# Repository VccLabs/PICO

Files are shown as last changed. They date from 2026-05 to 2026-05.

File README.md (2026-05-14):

# PICO

This repo is still under construction, all related files will be released very soon!
<div align="center">

PICO Development Board

# PICO

### A Tiny and Powerful Arduino-Compatible Development Board for Makers






</div>

---

## Introduction

**PICO**: a tiny but powerful Arduino-compatible development board built for makers who don't want to compromise. Measuring just **17.78 × 15.24 mm (0.7" × 0.6")**, PICO is small enough to disappear into wearables, drones, and pocket-sized prototypes, yet packs enough capability to drive serious projects.

At its core, PICO runs the proven **ATmega32U4** microcontroller and exposes **14 GPIOs**, giving you plenty of room to connect sensors, displays, motors, and just about anything else you can dream up. A built-in **WS2812 addressable RGB LED** on pin D5 adds a splash of color for status indication or pure fun. The board is fully **breadboard compatible**, so you can prototype quickly without extra adapters.

PICO is **open source** by design. All schematics, PCB layouts, and source files are available in this repository, so you're free to learn from it, modify it, or build on top of it.

---

## Features

- **Ultra-compact**: 17.78 × 15.24 mm (0.7" × 0.6") footprint
- **ATmega32U4**: microcontroller with native USB
- **14 GPIOs**: including PWM, ADC, I²C, SPI, and UART
- **Built-in WS2812 RGB LED**: (addressable, on pin D5)
- **Breadboard friendly**: castellated pins
- **Multiple power options**: USB and VIN
- **Arduino IDE compatible**: program it like any Arduino Leonardo
- **Fully open source**: schematics, PCB, and code freely available

---

## Specifications

| Category | Specification |
|---|---|
| **Microcontroller** | ATmega32U4 |
| **Architecture** | 8-bit AVR |
| **Clock Speed** | 16 MHz |
| **Flash Memory** | 32 KB (4 KB used by bootloader) |
| **SRAM** | 2.5 KB |
| **EEPROM** | 1 KB |
| **GPIO Pins** | 14 <!-- TODO: confirm digital vs analog split --> |
| **PWM Channels** | 3 (D4 D10 D11) |
| **Analog Inputs** | 5 (D4 D12 A0 A1 A2) |
| **Communication** | USB, I²C, SPI, UART |
| **Operating Voltage** | 5 V |
| **Input Voltage (VIN)** | 7V~15V or power from USB port |
| **DC Current per I/O Pin** | 40mA |
| **Onboard LED** | 1× WS2812 addressable RGB (1 × 1 mm) on D5 |
| **USB Connector** | USB Type-C (**Use USB Typ-A to Type-C cable, I forgot to add the 5.1K resistord on CC pins 🐸**) |
| **Dimensions** | 17.78 × 15.24 mm (0.7" × 0.6") |
| **Weight** | ~1.1 g |

---

## Pinout

<div align="center">

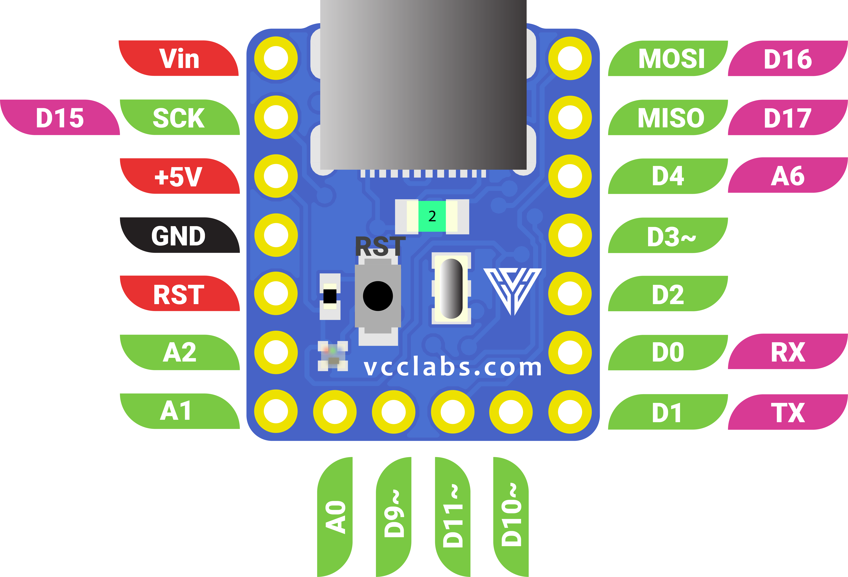
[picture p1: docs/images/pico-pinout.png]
PICO Pinout Diagram


</div>

| Pin | Type | Alternate Functions | Notes |
|---|---|---|---|
| Vin | Power (input)  | — | 7–15 V external supply |
| +5V | Power (output) | — | Regulated 5 V output |
| GND | Ground | — | Common ground |
| RST | Reset | — | Active low; pull to GND to reset |
| SCK | Digital | D15, SPI Clock | SPI bus |
| MOSI  | Digital | D16, SPI Master-Out | SPI bus |
| MISO  | Digital | D17, SPI Master-In | SPI bus |
| D4 | Digital | A6 (Analog In) | ADC capable |
| D3 ~  | Digital | PWM | PWM output |
| D2 | Digital | — | General-purpose I/O |
| D0 | Digital | RX (UART) | Serial receive |
| D1 | Digital | TX (UART) | Serial transmit |
| A0 | Analog | Digital I/O | ADC input |
| A1 | Analog | Digital I/O | ADC input |
| A2 | Analog | Digital I/O | ADC input |
| D9 ~  | Digital | PWM | PWM output |
| D10 ~ | Digital | PWM | PWM output |
| D11 ~ | Digital | PWM | PWM output |
| D5 | Digital | WS2812 RGB LED (onboard) | Connected to onboard RGB LED |

---

## Getting Started

### 1. Install the Arduino IDE

Download and install the latest **[Arduino IDE](https://www.arduino.cc/en/software)** (version 2.x recommended).

### 2. Add the PICO Board

<!-- TODO: confirm — does PICO work out-of-the-box as "Arduino Leonardo", or do you provide a custom board package? -->

In Arduino IDE, go to **Tools → Board → Board Manager** and select **Arduino Leonardo**, PICO is fully Leonardo-compatible.

### 3. Connect PICO

Plug PICO into your computer using a USB cable (**Use USB Typ-A to Type-C cable, I forgot to add the 5.1K resistord on CC pins 🐸**). The onboard RGB LED will light up briefly to confirm power.

###  Using FastLED

If you prefer **[FastLED](https://github.com/FastLED/FastLED)** over Adafruit NeoPixel, PICO works just as well with it. FastLED is a powerful, performance-focused library with built-in color palettes, HSV support, and smooth animation helpers.

### Install FastLED

In the Arduino IDE, go to **Sketch → Include Library → Manage Libraries…**, search for **FastLED**, and click **Install**.

### 4. Upload Your First Sketch

**Blink LED using FastLED library (Example from the library itself, don't forget to change the Data pin to D5):**

```cpp
#include <Arduino.h>
#include <FastLED.h>

// How many leds do we have?
#define NUM_LEDS 1

#define DATA_PIN 5 // LED pin
#define CLOCK_PIN 13

// Define the array of leds
CRGB leds[NUM_LEDS];

void setup() { 
    //Serial.begin(9600);
    //Serial.println("BLINK setup starting");

    FastLED.addLeds<NEOPIXEL, DATA_PIN>(leds, NUM_LEDS); 
}

void loop() { 
  //Serial.println("BLINK");
  
  // Turn the LED on, then pause
  leds[0] = CRGB::Red;
  FastLED.show();
  delay(500);
  
  // Now turn the LED off, then pause
  leds[0] = CRGB::Black;
  FastLED.show();
  delay(500);
}
```

Click **Upload** — and you're up and running. 

---

## Hardware

All hardware design files are open and available in the [`/hardware`](hardware) folder:

- **Schematics** — `hardware/PICO V1.0.pdf.pdf`
- **PCB Files** — `hardware/pcb/` (Eagle source files)

> Designed in **Eagle**. Feel free to fork and remix.

---

## Onboard RGB LED

PICO features a single **WS2812B addressable RGB LED** connected to **digital pin D5**. Use the [Adafruit NeoPixel](https://github.com/adafruit/Adafruit_NeoPixel) or [FastLED](https://github.com/FastLED/FastLED) libraries to control it.

See [`examples/01_Blink_RGB`](examples/01_Blink_RGB) for a minimal working sketch.

---

## Powering PICO

PICO can be powered in two ways:

| Source | Voltage | Notes |
|---|---|---|
| **USB** | 5 V | Plug-and-play for programming and power |
| **VIN pin** | 7V~15V | For battery or external supply |

> ⚠️ Do **not** apply power to USB and VIN simultaneously unless you understand the implications.

---

##  Community & Support

Got questions, ideas, or want to share what you built with PICO?

-  **Discussions**: [GitHub Discussions](https://github.com/VccLabs/PICO/discussions)
-  **Issues / Bugs**: [Open an issue](https://github.com/VccLabs/PICO/issues)
-  **Website**: [vcclabs.com](https://vcclabs.com)
-  **Email**: thevcclabs@gmail.com

---

## Contributing

Contributions are welcome! Whether it's a bug fix, a new example sketch, or documentation improvements, feel free to open a pull request.

---

## License

- **Software & examples** are licensed under the [MIT License](LICENSE).
- **Hardware design files** are licensed under the [Creative Commons Attribution 4.0 International License (CC BY 4.0)](https://creativecommons.org/licenses/by/4.0/).

You are free to use, modify, and distribute - including for commercial purposes - provided you credit **Vcc Labs** as the original creator.

---
https://github.com/fastled/fastled
## 🙏 Acknowledgments

PICO was made possible thanks to:

- The **78 backers** who supported us on [Kickstarter](https://www.kickstarter.com/projects/vcclabs/pico-a-tiny-and-powerful-development-board-for-makers) 🚀
- The open-source hardware community
- The [Arduino](https://arduino.cc), [Sparkfun](https://sparkfun.com), [FastLED](https://github.com/fastled/fastled), and [Adafruit](https://adafruit.com) teams for their incredible libraries and tools

---

<div align="center">

**Built with ❤️ by [Vcc Labs](https://vcclabs.com)**

</div>

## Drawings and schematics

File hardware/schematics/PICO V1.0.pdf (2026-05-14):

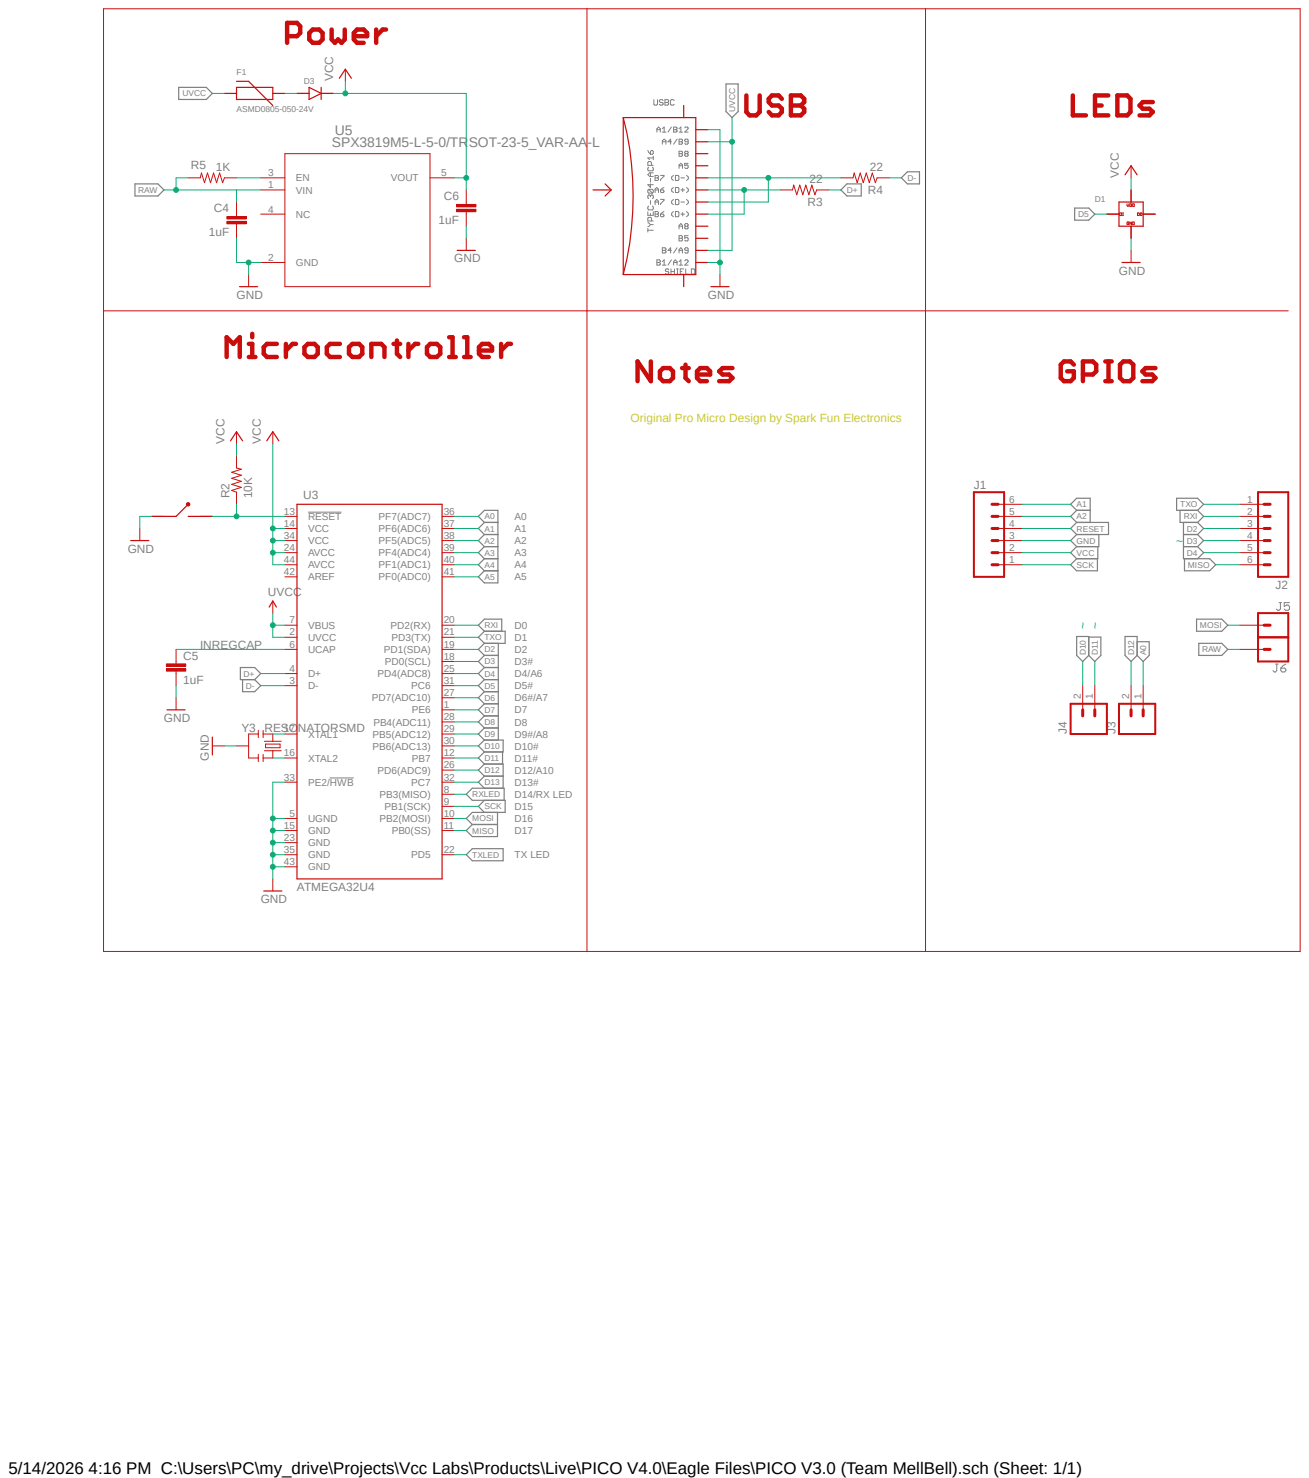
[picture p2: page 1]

Original Pro Micro Design by Spark Fun Electronics

5/14/2026 4:16 PM C:\Users\PC\my_drive\Projects\Vcc Labs\Products\Live\PICO V4.0\Eagle Files\PICO V3.0 (Team MellBell).sch (Sheet: 1/1)

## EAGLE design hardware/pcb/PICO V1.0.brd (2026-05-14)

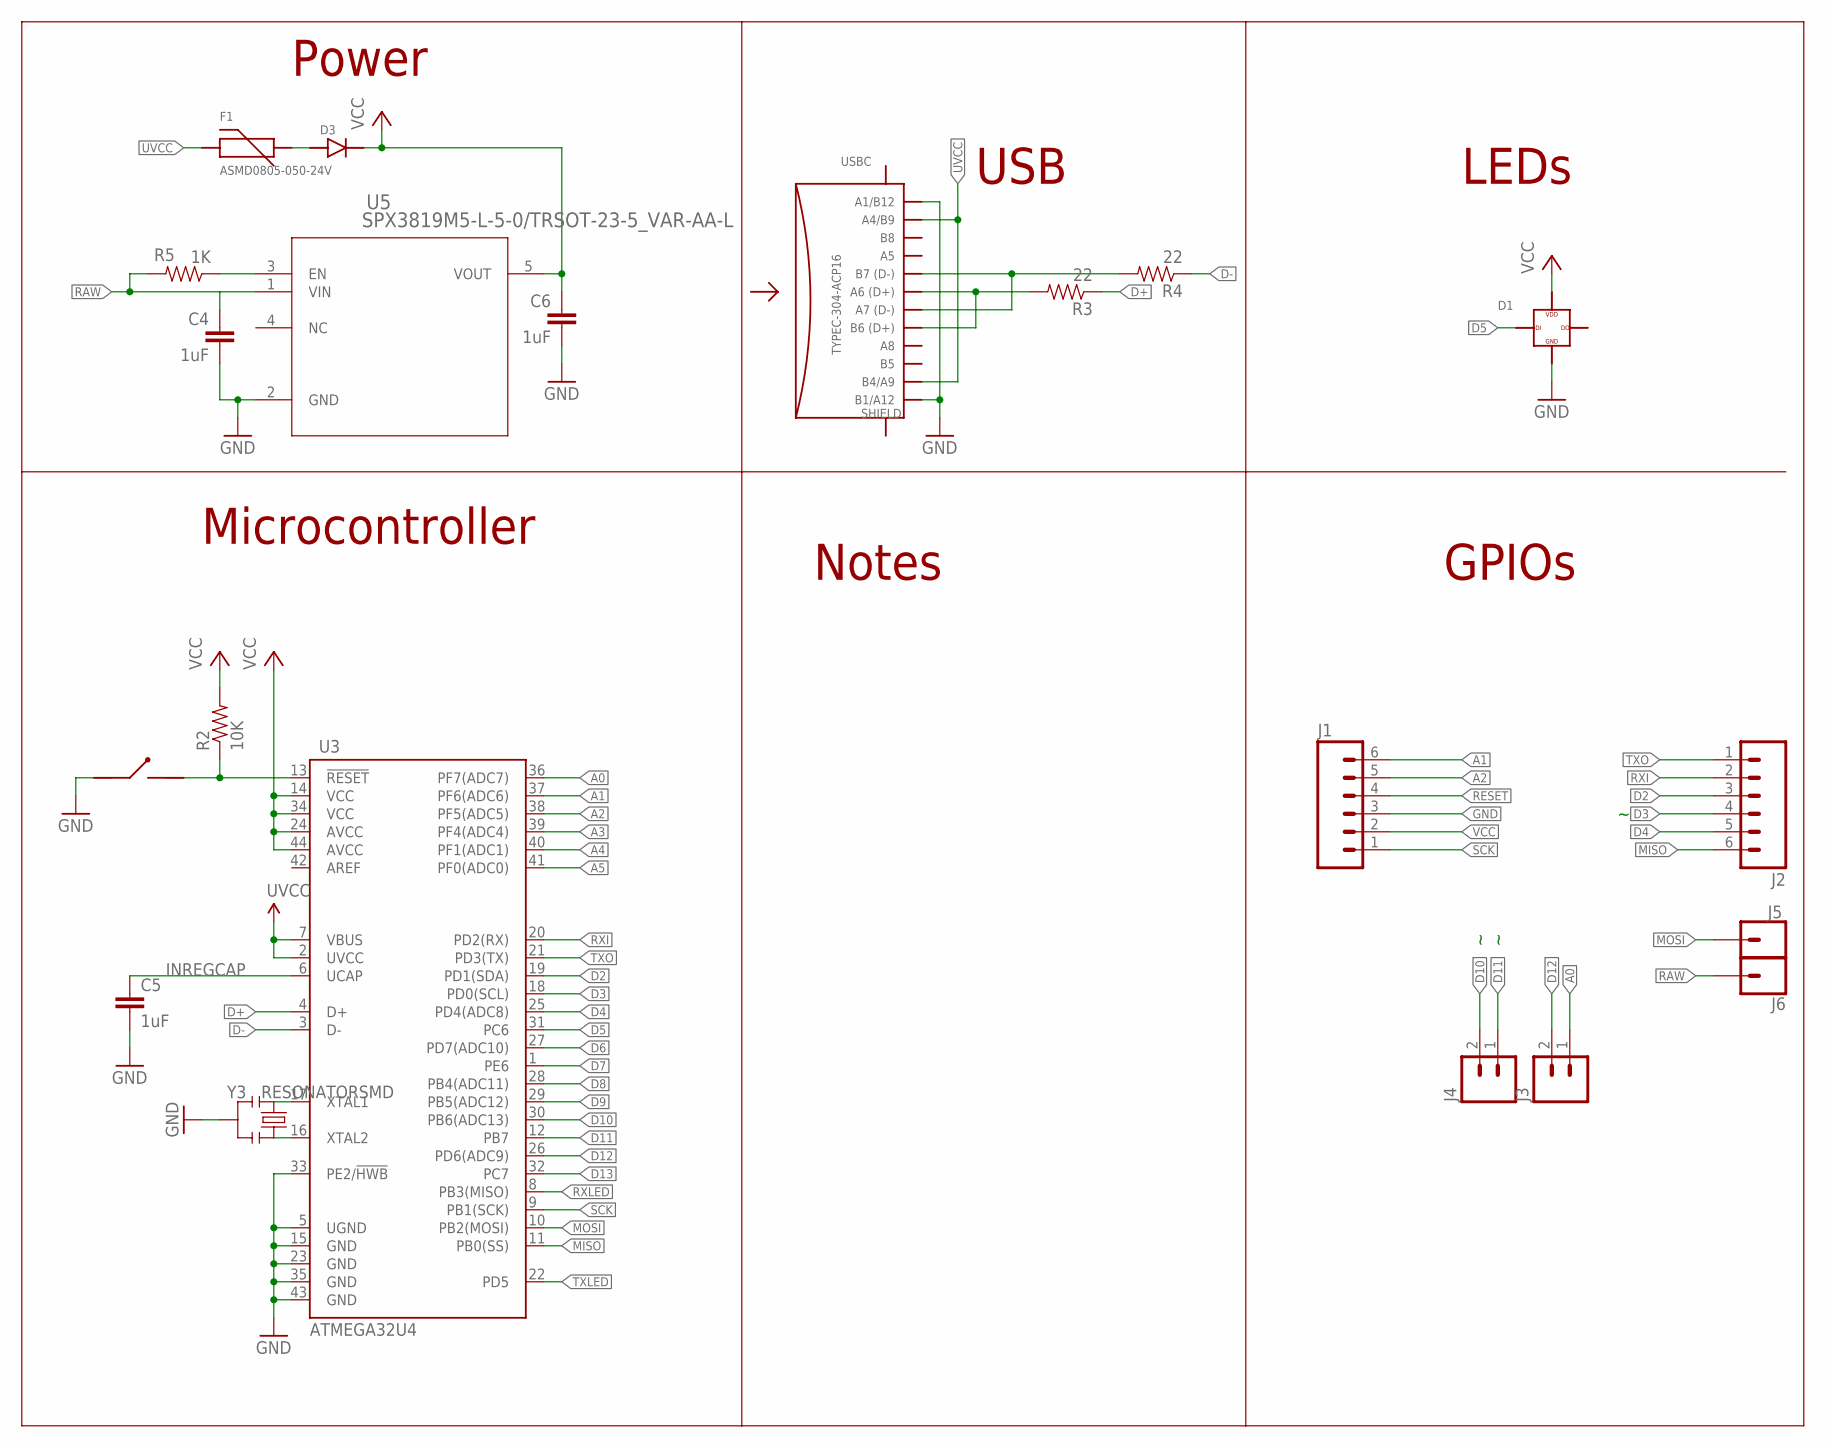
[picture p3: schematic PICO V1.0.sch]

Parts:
C4, C5, C6: 1uF; 0402-CAP
D1: XL-1010RGBC-WS2812B
D3: 1N4148W-TP
F1: ASMD0805-050-24V
J1, J2: M06SILK_FEMALE_PTH; 1X06
J3, J4: M02PTH; 1X02
J5, J6: CONN_01; 1X01
R2: 10K; 0402-RES
R3, R4: 22; 0402-RES
R5: 1K; 0402-RES
S1: B3U-1000P
U3: ATMEGA32U4; QFN-44-NOPAD_1:1-OUTFAKES
U5: SPX3819M5-L-5-0/TRSOT-23-5_VAR-AA-L; TPSPX3819M5-L-5-0/3
USBC: TYPEC-304-ACP16
Y3: RESONATORSMD; RESONATOR-SMD

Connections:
A0: J3.1, U3.36 (PF7(ADC7))
A1: J1.6, U3.37 (PF6(ADC6))
A2: J1.5, U3.38 (PF5(ADC5))
A3: U3.39 (PF4(ADC4))
A4: U3.40 (PF1(ADC1))
A5: U3.41 (PF0(ADC0))
D2: J2.3, U3.19 (PD1(SDA))
D3: J2.4, U3.18 (PD0(SCL))
D4: J2.5, U3.25 (PD4(ADC8))
D5: D1.4, U3.31 (PC6)
D6: U3.27 (PD7(ADC10))
D7: U3.1 (PE6)
D8: U3.28 (PB4(ADC11))
D9: U3.29 (PB5(ADC12))
D10: J4.2, U3.30 (PB6(ADC13))
D11: J4.1, U3.12 (PB7)
D12: J3.2, U3.26 (PD6(ADC9))
D13: U3.32 (PC7)
D+: R3.1, U3.4 (D+)
D-: R4.1, U3.3 (D-)
GND: C4.2, C5.2, C6.2, D1.3, J1.3, S1.1, U3.5 (UGND), U3.15 (GND), U3.23 (GND), U3.33 (PE2/!HWB), U3.35 (GND), U3.43 (GND), U5.2 (GND), USBC.A1/B12, USBC.B1/A12, Y3.2
INREGCAP: C5.1, U3.6 (UCAP)
MISO: J2.6, U3.11 (PB0(SS))
MOSI: J5.1, U3.10 (PB2(MOSI))
unnamed: U3.16 (XTAL2), Y3.3
unnamed: U3.17 (XTAL1), Y3.1
unnamed: R5.1, U5.3 (EN)
unnamed: D3.1, F1.2
unnamed: R3.2, USBC.A6, USBC.B6
unnamed: R4.2, USBC.A7, USBC.B7
RAW: C4.1, J6.1, R5.2, U5.1 (VIN)
RESET: J1.4, R2.1, S1.2, U3.13 (!RESET)
RXI: J2.2, U3.20 (PD2(RX))
RXLED: U3.8 (PB3(MISO))
SCK: J1.1, U3.9 (PB1(SCK))
TXLED: U3.22 (PD5)
TXO: J2.1, U3.21 (PD3(TX))
UVCC: F1.1, U3.2 (UVCC), U3.7 (VBUS), USBC.A4/B9, USBC.B4/A9
VCC: C6.1, D1.2, D3.2, J1.2, R2.2, U3.14 (VCC), U3.24 (AVCC), U3.34 (VCC), U3.44 (AVCC), U5.5 (VOUT)

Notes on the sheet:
Power
USB
LEDs
Microcontroller
GPIOs
Notes

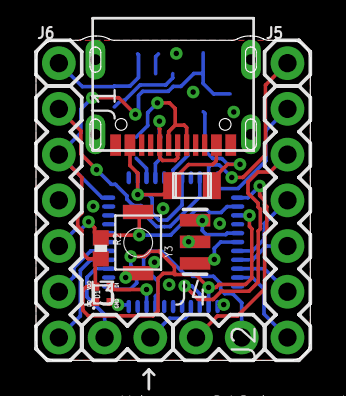
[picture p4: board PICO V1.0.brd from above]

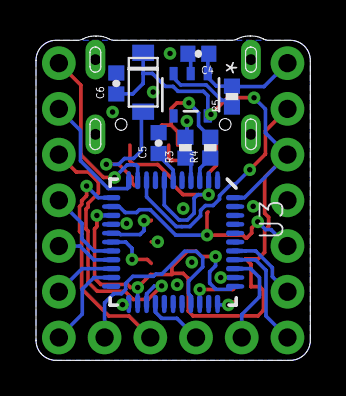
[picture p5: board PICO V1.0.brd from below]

Board: 2 copper layers, 15.2 x 18.0 mm, 21 parts (9 on the bottom side), 29 nets.

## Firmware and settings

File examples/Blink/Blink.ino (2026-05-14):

/// @file    Blink.ino
/// @brief   Blink the first LED of an LED strip
/// @example Blink.ino

#include <Arduino.h>
#include <FastLED.h>

// How many leds in your strip?
#define NUM_LEDS 1

// For led chips like WS2812, which have a data line, ground, and power, you just
// need to define DATA_PIN.  For led chipsets that are SPI based (four wires - data, clock,
// ground, and power), like the LPD8806 define both DATA_PIN and CLOCK_PIN
// Clock pin only needed for SPI based chipsets when not using hardware SPI
#define DATA_PIN 5
#define CLOCK_PIN 13

// Define the array of leds
CRGB leds[NUM_LEDS];

void setup() { 
    //Serial.begin(9600);
    //Serial.println("BLINK setup starting");
    
    // Uncomment/edit one of the following lines for your leds arrangement.
    // ## Clockless types ##
    FastLED.addLeds<NEOPIXEL, DATA_PIN>(leds, NUM_LEDS);  // GRB ordering is assumed
    
    //Serial.println("BLINK setup complete");
    // FastLED.addLeds<SM16824E, DATA_PIN, RGB>(leds, NUM_LEDS);  // RGB ordering (uses SM16824EController)
    // FastLED.addLeds<SM16703, DATA_PIN, RGB>(leds, NUM_LEDS);
    // FastLED.addLeds<TM1829, DATA_PIN, RGB>(leds, NUM_LEDS);
    // FastLED.addLeds<TM1812, DATA_PIN, RGB>(leds, NUM_LEDS);
    // FastLED.addLeds<TM1809, DATA_PIN, RGB>(leds, NUM_LEDS);
    // FastLED.addLeds<TM1804, DATA_PIN, RGB>(leds, NUM_LEDS);
    // FastLED.addLeds<TM1803, DATA_PIN, RGB>(leds, NUM_LEDS);
    // FastLED.addLeds<UCS1903, DATA_PIN, RGB>(leds, NUM_LEDS);
    // FastLED.addLeds<UCS1903B, DATA_PIN, RGB>(leds, NUM_LEDS);
    // FastLED.addLeds<UCS1904, DATA_PIN, RGB>(leds, NUM_LEDS);
    // FastLED.addLeds<UCS2903, DATA_PIN, RGB>(leds, NUM_LEDS);
    // FastLED.addLeds<WS2812, DATA_PIN, RGB>(leds, NUM_LEDS);  // GRB ordering is typical
    // FastLED.addLeds<WS2852, DATA_PIN, RGB>(leds, NUM_LEDS);  // GRB ordering is typical
    // FastLED.addLeds<WS2812B, DATA_PIN, RGB>(leds, NUM_LEDS);  // GRB ordering is typical
    // FastLED.addLeds<GS1903, DATA_PIN, RGB>(leds, NUM_LEDS);
    // FastLED.addLeds<SK6812, DATA_PIN, RGB>(leds, NUM_LEDS);  // GRB ordering is typical
    // FastLED.addLeds<SK6822, DATA_PIN, RGB>(leds, NUM_LEDS);
    // FastLED.addLeds<APA106, DATA_PIN, RGB>(leds, NUM_LEDS);
    // FastLED.addLeds<PL9823, DATA_PIN, RGB>(leds, NUM_LEDS);
    // FastLED.addLeds<SK6822, DATA_PIN, RGB>(leds, NUM_LEDS);
    // FastLED.addLeds<WS2811, DATA_PIN, RGB>(leds, NUM_LEDS);
    // FastLED.addLeds<WS2813, DATA_PIN, RGB>(leds, NUM_LEDS);
    // FastLED.addLeds<APA104, DATA_PIN, RGB>(leds, NUM_LEDS);
    // FastLED.addLeds<WS2811_400, DATA_PIN, RGB>(leds, NUM_LEDS);
    // FastLED.addLeds<GE8822, DATA_PIN, RGB>(leds, NUM_LEDS);
    // FastLED.addLeds<GW6205, DATA_PIN, RGB>(leds, NUM_LEDS);
    // FastLED.addLeds<GW6205_400, DATA_PIN, RGB>(leds, NUM_LEDS);
    // FastLED.addLeds<LPD1886, DATA_PIN, RGB>(leds, NUM_LEDS);
    // FastLED.addLeds<LPD1886_8BIT, DATA_PIN, RGB>(leds, NUM_LEDS);
    // ## Clocked (SPI) types ##
    // FastLED.addLeds<LPD6803, DATA_PIN, CLOCK_PIN, RGB>(leds, NUM_LEDS);  // GRB ordering is typical
    // FastLED.addLeds<LPD8806, DATA_PIN, CLOCK_PIN, RGB>(leds, NUM_LEDS);  // GRB ordering is typical
    // FastLED.addLeds<WS2801, DATA_PIN, CLOCK_PIN, RGB>(leds, NUM_LEDS);
    // FastLED.addLeds<WS2803, DATA_PIN, CLOCK_PIN, RGB>(leds, NUM_LEDS);
    // FastLED.addLeds<SM16716, DATA_PIN, CLOCK_PIN, RGB>(leds, NUM_LEDS);
    // FastLED.addLeds<P9813, DATA_PIN, CLOCK_PIN, RGB>(leds, NUM_LEDS);  // BGR ordering is typical
    // FastLED.addLeds<DOTSTAR, DATA_PIN, CLOCK_PIN, RGB>(leds, NUM_LEDS);  // BGR ordering is typical
    // FastLED.addLeds<APA102, DATA_PIN, CLOCK_PIN, RGB>(leds, NUM_LEDS);  // BGR ordering is typical
    // FastLED.addLeds<SK9822, DATA_PIN, CLOCK_PIN, RGB>(leds, NUM_LEDS);  // BGR ordering is typical
}

void loop() { 
  //Serial.println("BLINK");
  
  // Turn the LED on, then pause
  leds[0] = CRGB::Red;
  FastLED.show();
  delay(500);
  
  // Now turn the LED off, then pause
  leds[0] = CRGB::Black;
  FastLED.show();
  delay(500);
}

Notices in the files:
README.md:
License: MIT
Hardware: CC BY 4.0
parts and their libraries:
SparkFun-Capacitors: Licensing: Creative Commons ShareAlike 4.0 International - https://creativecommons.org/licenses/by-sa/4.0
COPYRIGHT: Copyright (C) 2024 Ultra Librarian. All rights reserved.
